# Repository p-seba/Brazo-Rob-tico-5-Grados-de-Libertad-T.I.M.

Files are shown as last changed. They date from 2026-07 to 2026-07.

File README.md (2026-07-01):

# Brazo Robótico de 5 Grados de Libertad - T.I.M.
Proyecto del Taller Inicial de Mecatrónica, Facultad de Ingeniería, UNCuyo. 

En este repositorio encontrarás todos los archivos asociados a la realización y presentación final del proyecto.    

Aplicaciones utilizadas: 
* Autodesk Fusion
* KiCad
* Visual Studio Code (PlatformIO)

En la carpeta de **Código** se encuentra una recopilación de todos los programas utilizados durante las pruebas y el código final. 

En la carpeta de **Diseño 3D** están los archivos de modelado y dos renders. Todo el diseño fue realizado por el grupo, excepto por el componente de la garra, el cual es una modificación del diseño original de **Julián Herrera**, disponible en: https://grabcad.com/library/gripper-and-servo-mg90s-1 

En la carpeta **PCB** están subidos los archivos de KiCad utilizados para diseñar las conexiones finales.  

En la carpeta **Documentación** están subidos todos los trabajos prácticos asociados a la materia y el informe final presentado en la mesa de examen. 

## Enlaces de interés 

* **Diseño en Fusion:** https://a360.co/4xZ3YgB 
* **Informe:** 

### Herramientas:
* **Autodesk Fusion:** https://www.autodesk.com/latam/products/fusion-360/overview
* **KiCad:** https://www.kicad.org/
* **Visual Studio Code:** https://code.visualstudio.com/
* **PlatformIO:** https://platformio.org/

---
Ante cualquier consulta, contactar a: joaquin.winckler@gmail.com

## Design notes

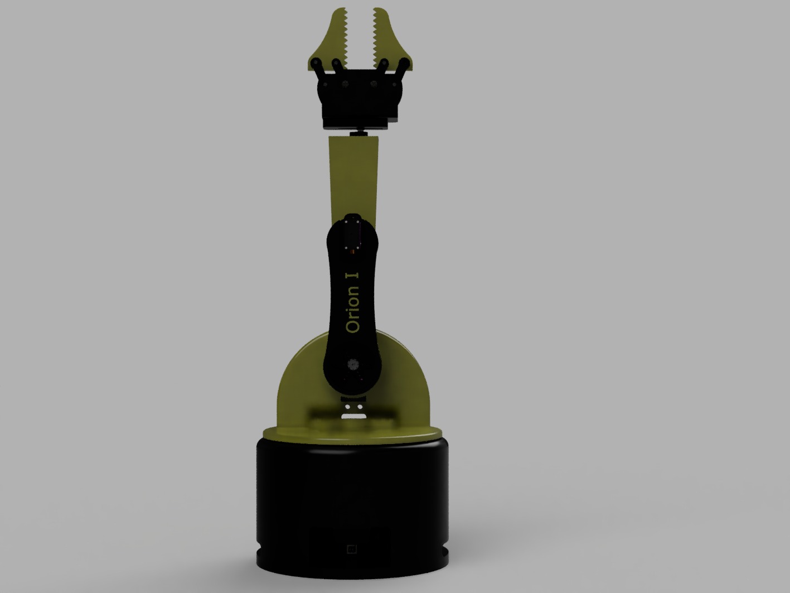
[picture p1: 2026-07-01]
Diseño 3d/Render 2.jpeg

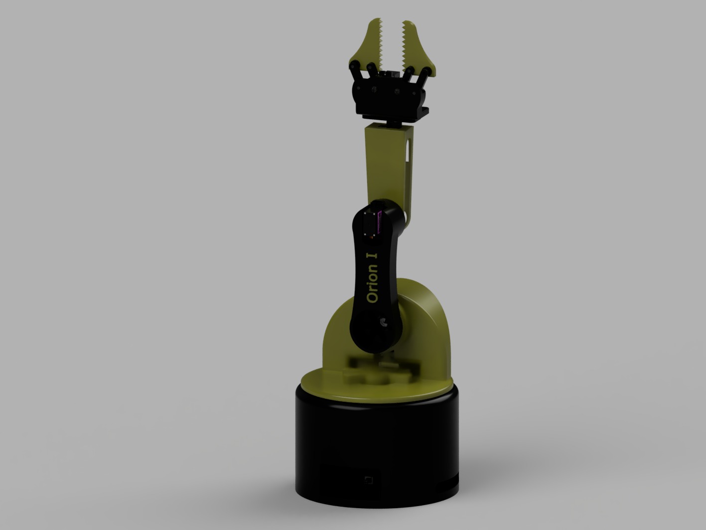
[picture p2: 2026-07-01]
Diseño 3d/Render 1.jpeg

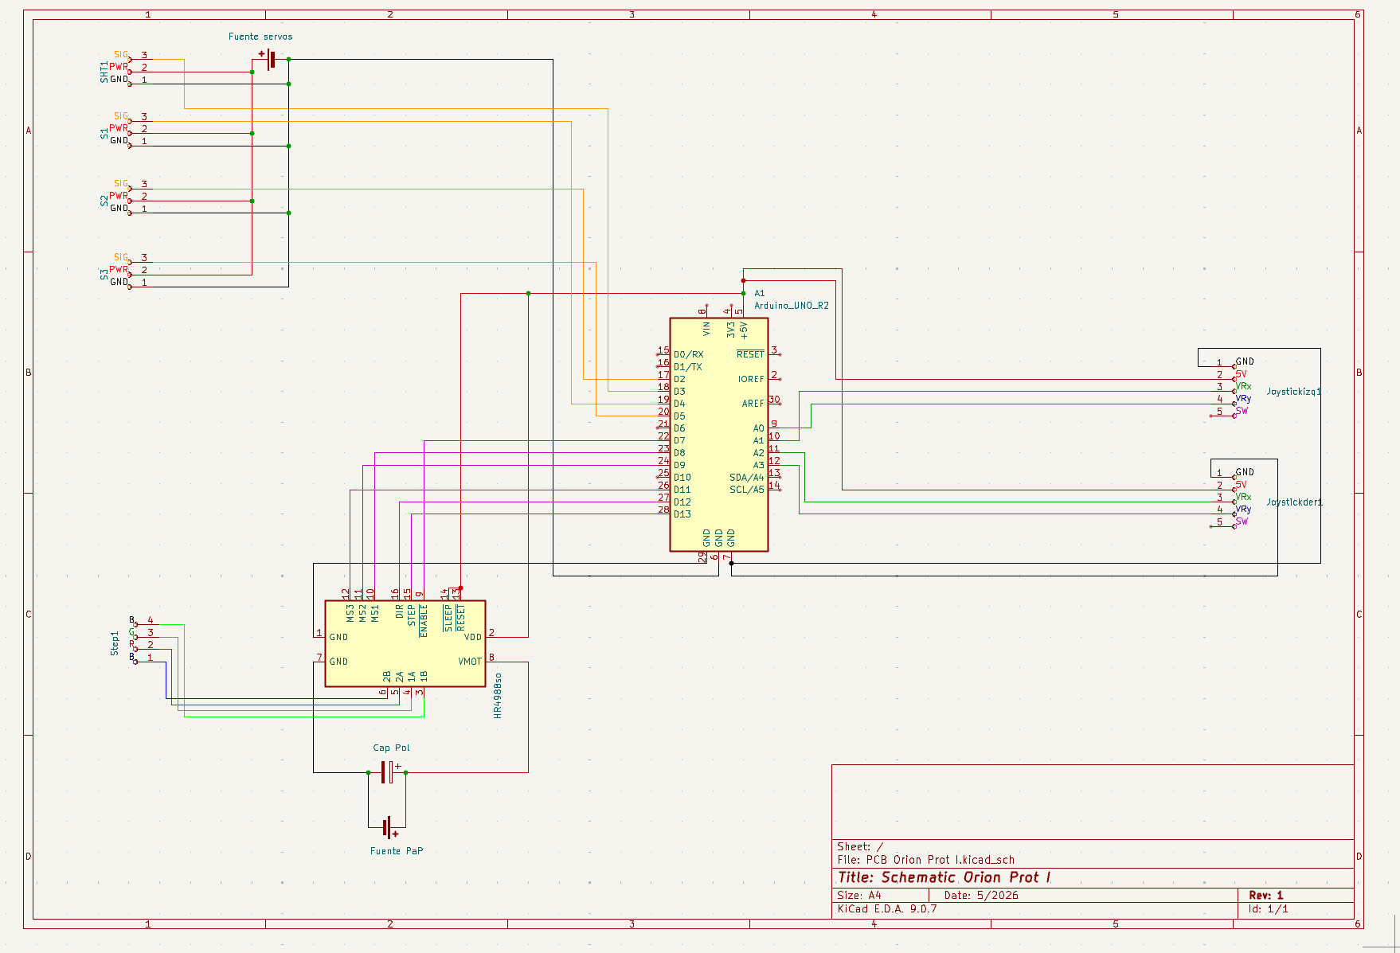
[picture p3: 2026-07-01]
PCB/Circuito.png

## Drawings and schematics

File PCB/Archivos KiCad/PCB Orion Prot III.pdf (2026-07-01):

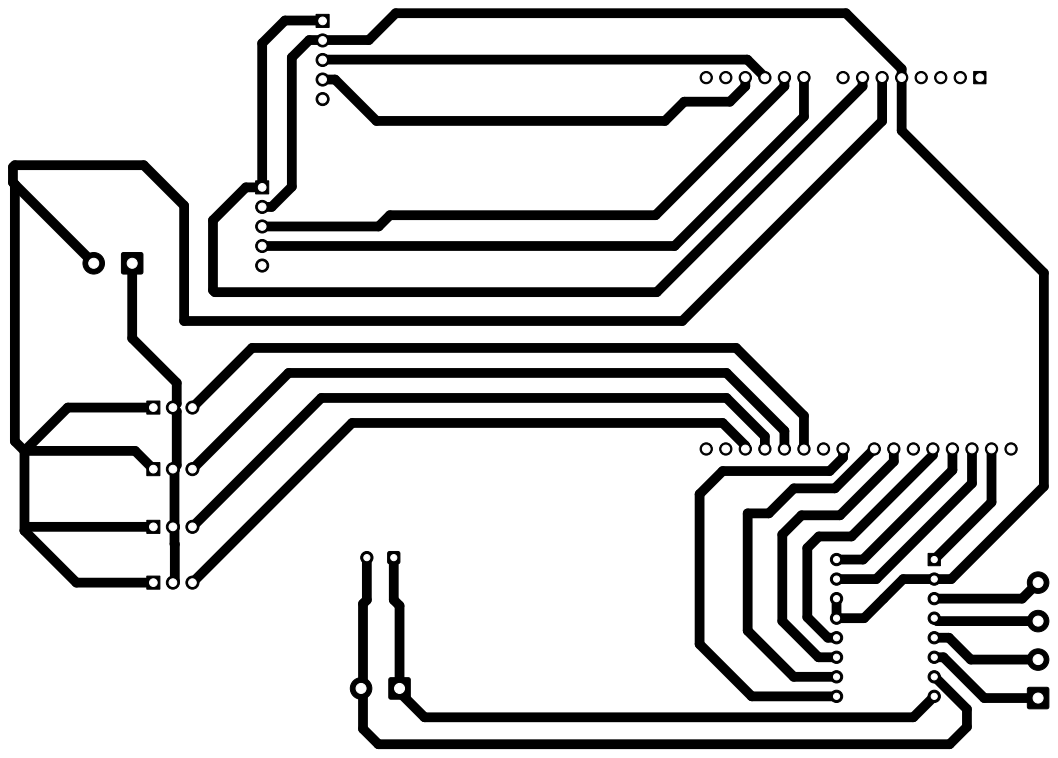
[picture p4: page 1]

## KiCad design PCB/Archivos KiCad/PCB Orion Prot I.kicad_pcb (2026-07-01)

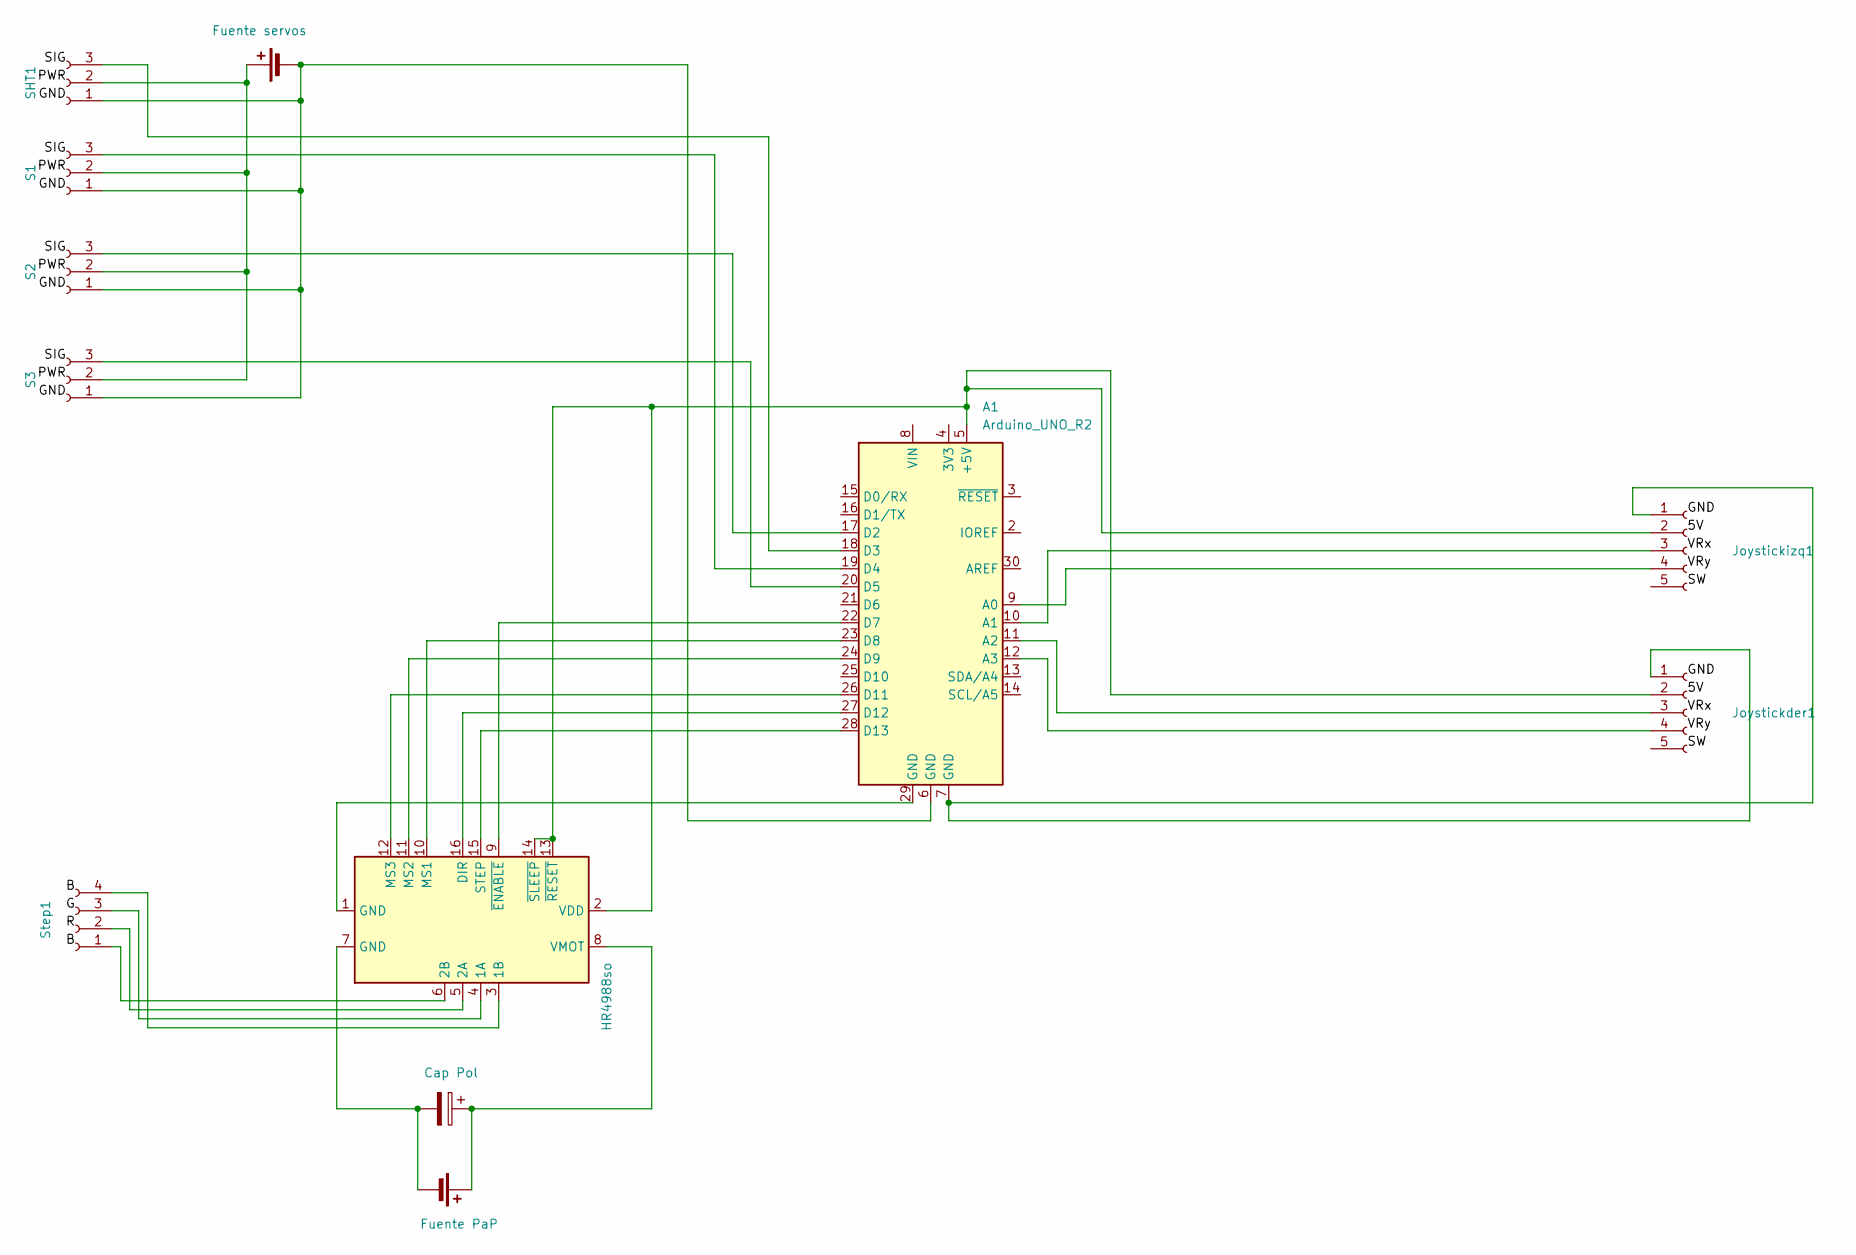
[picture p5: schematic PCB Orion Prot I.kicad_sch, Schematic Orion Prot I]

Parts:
A1: Arduino_UNO_R2
A2: HR4988so; Pololu_Breakout-16_15.2x20.3mm
BT1: Fuente servos; TerminalBlock_MaiXu_MX126-5.0-02P_1x02_P5.00mm
BT2: Fuente PaP; TerminalBlock_MaiXu_MX126-5.0-02P_1x02_P5.00mm
C2: Cap Pol; CP_Radial_D8.0mm_P3.50mm
Joystickder1: Conn_01x05_Socket; PinSocket_1x05_P2.54mm_Vertical
Joystickizq1: Conn_01x05_Socket; PinSocket_1x05_P2.54mm_Vertical
S1, S2, S3: Conn_01x03_Socket; PinHeader_1x03_P2.54mm_Vertical
SHT1: Conn_01x03_Socket; PinHeader_1x03_P2.54mm_Vertical
Step1: Conn_01x04_Socket; TerminalBlock_MaiXu_MX126-5.0-04P_1x04_P5.00mm

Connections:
unnamed: A1.5 (+5V), A2.2 (VDD), A2.13 (~RESET), A2.14 (~SLEEP), Joystickder1.2, Joystickizq1.2
unnamed: A1.9 (A0), Joystickizq1.4
unnamed: A1.10 (A1), Joystickizq1.3
unnamed: A1.11 (A2), Joystickder1.3
unnamed: A1.12 (A3), Joystickder1.4
unnamed: A1.17 (D2), S2.3
unnamed: A1.18 (D3), SHT1.3
unnamed: A1.19 (D4), S1.3
unnamed: A1.20 (D5), S3.3
unnamed: A1.22 (D7), A2.9 (~ENABLE)
unnamed: A1.23 (D8), A2.10 (MS1)
unnamed: A1.24 (D9), A2.11 (MS2)
unnamed: A1.26 (D11), A2.12 (MS3)
unnamed: A1.27 (D12), A2.16 (DIR)
unnamed: A1.28 (D13), A2.15 (STEP)
unnamed: A1.29 (GND), A2.1 (GND)
unnamed: A2.4 (1A), Step1.3
unnamed: A2.3 (1B), Step1.4
unnamed: A2.5 (2A), Step1.2
unnamed: A2.6 (2B), Step1.1
unnamed: A2.8 (VMOT), BT2.1 (+), C2.1
unnamed: BT1.1 (+), S1.2, S2.2, S3.2, SHT1.2
unnamed: A1.6 (GND), BT1.2 (-), S1.1, S2.1, S3.1, SHT1.1
unnamed: A2.7 (GND), BT2.2 (-), C2.2
unnamed: A1.7 (GND), Joystickder1.1, Joystickizq1.1

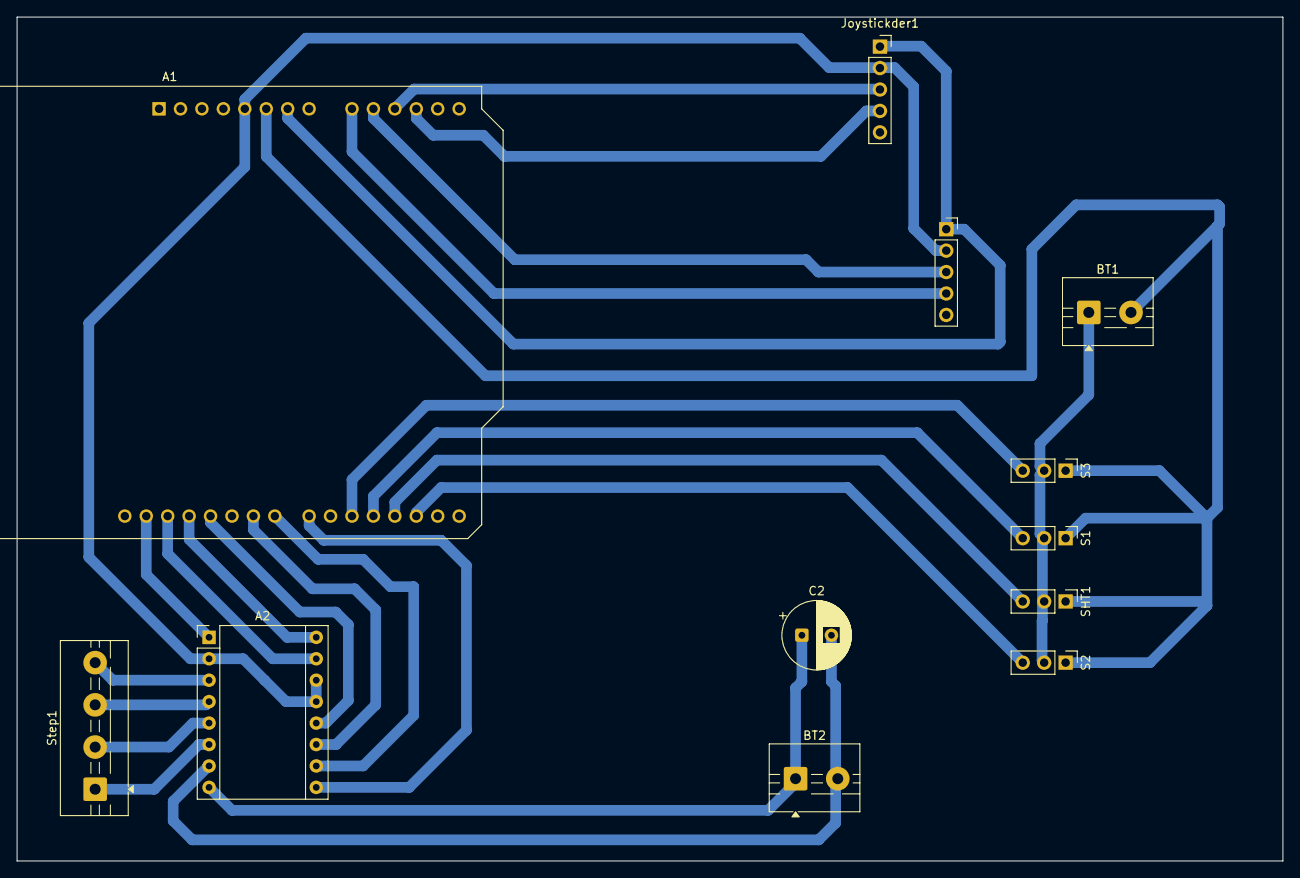
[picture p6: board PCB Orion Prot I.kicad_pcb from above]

Board: 2 copper layers, 150.0 x 100.0 mm, 12 parts (0 on the bottom side), 25 nets.

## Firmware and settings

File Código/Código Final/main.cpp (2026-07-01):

#include <Arduino.h>
#include <Servo.h>
#include <AccelStepper.h>

// SETEO JOYSTICKS

struct J{
  int j_pin; //pin al que esta conectado el joystick 
  float j_centro; // centro del joystick 
  float j_min; //valor minimo del joystick 
  float j_max; //valor maximo del joystick 
  float j_rango; //distancia del centro hasta un extremo (la menor)
  unsigned long j_lectura; //tiempo que paso desde la ultima lectura 
  const int j_tlectura; //tiempo que espera entre cada lectura
  const int j_cmedidas; //lecturas del joystick para determinar su centro 
  const int j_medidas; //cantidad de veces que se lee el joystick cada vez 
  float j_valor; //valor del joystick
  const int j_zonam; //zona muerta
  bool calibrado; //determina si se calculo el centro 
};

const int j_n = 4; //cantidad de joysticks 

J joy[j_n]{
  {A0, 512, 50, 973, 0, 0, 5, 50, 3, 0, 25, false}, //alto torque 0 
  {A1, 512, 50, 973, 0, 0, 5, 50, 3, 0, 25, false}, //1 codo sg90
  {A2, 512, 50, 973, 0, 0, 5, 50, 3, 0, 25, false}, //2 
  {A3, 512, 50, 973, 0, 0, 5, 50, 3, 0, 25, false} //3 
};

// SETEO SERVOS 

struct S{
  Servo servo; //crea el objeto Servo. 
  const int s_pin; //pin del servo 
  const int s_min; //grado minimo del servo 
  const int s_max; // grado maximo del servo 
  const int s_centro; //centro del servo 
  J* joy_ref; //puntero que almacena los datos de los joysticks 
  const int s_rango; //distancia del centro a los extremos 
  int s_posicion_a; //posicion actual del servo 
  int s_posicion_o; //posicion objetivo del servo
  const float s_vel; //cantidad de grados que se mueve por segundo
  float s_mov_grados; //movimiento en grados 
  float s_obj_grados; //movimiento objetivo en grados 
};

const int s_n = 3; //cantidad de servos asociados a movimiento 

S servos[s_n]{
  {Servo(), 8, 5, 175, 90, &joy[0], 85, 90, 90, 0.05, 0.0, 0.0}, //0
  {Servo(), 9, 5, 175, 90, &joy[1], 85, 90, 90, 0.05, 0.0, 0.0}, //1
  {Servo(), 10, 5, 175, 90, &joy[2], 85, 90, 90, 0.1, 0.0, 0.0} //2
}; 

// SETEO GARRA

struct G{
  Servo servo; //crea el objeto Servo. 
  const int g_pin; //pin del servo asociado a la garra
  const int g_min; //grado minimo de la garra
  const int g_max; //grado maximo de la garra 
  int g_posicion_a; //posicion actual del servo  
  const float g_vel; //tiempo entre cada movimiento del servo 
  const int bot_a; //pin del boton para abrir
  const int bot_c; // pin del boton para cerrar
  unsigned long t_ultimo_paso; // medicion de tiempo 
};

G garra{
  Servo(), 11, 5, 175, 90, 30, 12, 13,0
};

// SETEO MOTOR PASO A PASO
      
struct P{
  AccelStepper stepper; //crea el objeto stepper 
  const int p_enable; //prender el motor 
  const int p_dir; //determina la dirección del motor, 6
  const int p_step; //determina los pasos del motor, 5 
  const int p_ms1; //micropasos asociados al motor
  const int p_ms2; 
  const int p_ms3;
  J* joy_ref; //puntero que almacena datos de los joysticks 
  const float pv_max; //velocidad maxima 
  const float rampa; // "aceleracion"
  float v_ac; //velocidad actual 
};

P paso{
  AccelStepper(AccelStepper::DRIVER, 5 /*Step*/, 6 /*Dir*/) /*define el motor*/, 7, 6, 5, 4, 3, 2, &joy[3], 200.0, 0.08, 0.0
};

// CALIBRAR JOYSTICKS 

void calibrar(){

  //realiza el bucle, abarca los 4 joysticks 
  for ( int s = 0; s < j_n; s++){
    long sum = 0; //reinicia el valor de sum 

    for (int i = 0; i < joy[s].j_cmedidas; i++){
      sum += analogRead(joy[s].j_pin); //lee el joystick correpondiente una cierta cantidad de veces y las suma 
      delay(10); 
    }

    joy[s].j_centro = sum / joy[s].j_cmedidas; //le asigna como centro el cociente entre la suma y la cantidad de veces que se midio
    
    joy[s].j_valor = joy[s].j_centro; //inicializa el valor del joystick como su centro 

    //luego de determinar zona muerta curva 
    joy[s].j_max = 1023.0 - joy[s].j_centro - joy[s].j_zonam; //recalcula el valor maximo 
    joy[s].j_min = joy[s].j_centro - joy[s].j_zonam; //recalcula el valor minimo 

    joy[s].j_rango = min(joy[s].j_max, joy[s].j_min); //toma como que el joystick tiene el menor rango de movimiento para evitar forzar un lado
    joy[s].j_rango = joy[s].j_rango * 0.90; //utiliza solo el 90% del rango (evita que el movimiento sea mas rapido para un lado)
    joy[s].j_rango = max(joy[s].j_rango, 1.0); //evita que el rango sea 0  

  }

}

//VALOR JOYSTICKS 

float j_val (J* joy /*define la variable a partir del puntero*/) {

  //lee el joystick cada 20ms
  if (millis() /* tiempo desde que el arduino esta ejecutando codigo */ - joy->j_lectura >= joy->j_tlectura){
    joy->j_lectura = millis(); //le modifica el tiempo de la ultima lectura al joystick 
        
    long sum = 0;

    //realiza 3 lecturas del joystick 
    for (int i = 0; i < joy->j_medidas; i++){
      sum += analogRead(joy->j_pin);
    }

    joy->j_valor = sum/joy->j_medidas; //le asigna como valor final al joystick el promedio de las lecturas 
    }

  //aplica la zona muerta
  float diff = joy->j_valor - joy->j_centro; //diferencia entre el valor medido y el centro 
  float signo = (diff >= 0) ? 1.00 : -1.00; //si la diferencia es mayor que 0, le asigna 1 y si no -1 (positivo y negativo)
  float diff_a = fabs(diff) - joy->j_zonam; //cuanto "salio" el joystick de la zona muerta 

  //si el joystick se movio afuera de la zona muerta 
  if (diff_a > 0){ 
    float fraccion = diff_a / joy->j_rango; //determina el movimiento con un valor entre 0 y 1 (0 no mov, 1 se mueve todo el rango)
    fraccion = constrain(fraccion, 0.0, 1.0); //limita el valor para evitar errores 
    fraccion = pow(fraccion, 1.3); //eleva el resultado a 1.3, disminuye la sensibilidad cerca del centro 

    return (fraccion * signo); //valor final con direccion incluida. 

  }

  //si no se movio afuera de la zona muerta 
  else{ 
    return 0.0;
  }
        
}

// INICIO SERVOS 

void inicio(){

  //asigna los pines a cada uno de los motores y los mueve al centro 
  for (int i = 0; i < s_n; i++){
    servos[i].servo.attach(servos[i].s_pin); //asignacion de pines
    servos[i].s_posicion_a = servos[i].s_centro; //posicion actual = centro 
    servos[i].servo.write(90); //mueve los servos al centro 
  }

  //GARRA
  garra.servo.attach(garra.g_pin); //asigna el pine 
  garra.servo.write(garra.g_posicion_a); //mueve a la posicion inicial 
  //pines de los botones de los joysticks, resistencia interna 
  pinMode(garra.bot_a, INPUT_PULLUP); //abrir 
  pinMode(garra.bot_c, INPUT_PULLUP); //cerrar
}

// MOVIMIENTO SERVOS  

//Determina la cantidad de grados a mover, servos[h].s_posicion_o

int mover(int h, float j_valor){

  // si el joystick esta dentro de la zona muerta 
  if (fabs(j_valor) == 0.0){
    servos[h].s_posicion_o = servos[h].s_posicion_a; // posicion obj = posicion actual, no movimiento 
    servos[h].s_obj_grados = 0.0; // grados a mover = 0 
    return servos[h].s_posicion_o; // mantiene la posicion actual 
  }

  //si no esta en la zona muerta 

  servos[h].s_obj_grados += fabs(j_valor); // determina la cantidad de grados objetivos a mover, PROBAR MULTIPLICANDO POR 0.75, ETC.

  //si hay mas de un grado para mover 
  if (servos[h].s_obj_grados >= 1.0){
 
    int pasos_obj = (int)servos[h].s_obj_grados; //transforma s_obj_grados a una variable entera, solo toma la parte entera 
    servos[h].s_obj_grados -= pasos_obj;  //deja en s_obj_grados solo la parte decimal para aprovecharla en la sig iteracion 

    int nueva_pos; //define la nueva posicion del motor 

    //si se mueve para la derecha 
    if (j_valor > 0){
      nueva_pos = servos[h].s_posicion_o + pasos_obj; // Calcula la nueva posicion como la antigua posicion objetivo + la cantidad de pasos 
    } 
    //si se mueve para la izquierda 
    else {
      nueva_pos = servos[h].s_posicion_o - pasos_obj; // Calcula la nueva posicion como la antigua posicion objetivo - la cantidad de pasos 
    }

    //limita el nuevo valor de posicion a los maximos y minimos preestablecidos del servo 
    nueva_pos = constrain(nueva_pos, servos[h].s_min, servos[h].s_max);
    //limita la nueva posicion a valores cercanos a la posicion actual para evitar movimientos bruscos 
    nueva_pos = constrain(nueva_pos, servos[h].s_posicion_a - 5, servos[h].s_posicion_a + 5);

    servos[h].s_posicion_o = nueva_pos;
  }

  return servos[h].s_posicion_o; //devuelve la posicion objetivo 

}

// Realiza el movimiento, servos[i].s_posicion_a

void actualizacion(int i){

  int diff = servos[i].s_posicion_o - servos[i].s_posicion_a; //diferencia entre el obj y la actual  

  //si hay 1 grado o menos para mover 
  if (abs(diff) <= 1){
    servos[i].s_mov_grados = 0.0; //no devuelve movimiento 
    return; //pasa al siguiente motor 
  }

  //si hay movimiento, lo acumula como el ultimo movimiento + velocidad
  servos[i].s_mov_grados += servos[i].s_vel;

  // solo mueve cuando acumuló al menos 1 grado
  if (servos[i].s_mov_grados >= 1.0){

    int pasos = (int)servos[i].s_mov_grados; //guarda solo la parte entera del movimiento 
    servos[i].s_mov_grados -= pasos; // guarda la parte decimal del movimiento para futuras iteraciones 

    pasos = min(pasos, abs(diff)); //limita el paso a 5 grados 
      
    //determina para que lado se mueve y limita el movimiento 
    servos[i].s_posicion_a += (diff > 0) ? pasos : -pasos; //si la resta es positiva se mueve para la derecha, pos_ac = pos_ac + pasos, analogo izq
    servos[i].s_posicion_a = constrain(servos[i].s_posicion_a, servos[i].s_min, servos[i].s_max); //limita la nueva posicion del servo para que no salga de los limites 
    servos[i].servo.write(servos[i].s_posicion_a); //realiza el movimiento del servo 
  }
}
     
//GARRA

void agarrar(){
  
  //si pasaron 50 ms o mas entre pasos 
  if (millis() - garra.t_ultimo_paso >= garra.g_vel){

    garra.t_ultimo_paso = millis(); //actualiza el tiempo 


    if ((digitalRead(garra.bot_a) == LOW) && (digitalRead(garra.bot_c) == LOW)){
      garra.g_posicion_a = 170;  //si tocas los botones al mismo tiempo se abre la garra 
    }
    //si el boton de abrir se presiona se abre 5 grados
    else if (digitalRead(garra.bot_a) == LOW){
      garra.g_posicion_a += 5; 
    }
    //si el boton de cerrar se presiona se cierra 5 grados 
    else if (digitalRead(garra.bot_c) == LOW){
      garra.g_posicion_a -= 5;
    }

    garra.g_posicion_a = constrain(garra.g_posicion_a, garra.g_min, garra.g_max); //limita la posicion por seguridad 
    garra.servo.write(garra.g_posicion_a); //mueve la garra
  }

}

//CONFIGURACION MOTOR PASO A PASO 

void p_config(){

  //tipo de pin de los micro pasos y enable 
  pinMode(paso.p_ms1, OUTPUT); 
  pinMode(paso.p_ms2, OUTPUT);
  pinMode(paso.p_ms3, OUTPUT);
  pinMode(paso.p_enable, OUTPUT);

  //setea los micropasos a 1/4, 800 una vuelta 
  digitalWrite(paso.p_ms1, LOW);
  digitalWrite(paso.p_ms2, HIGH); 
  digitalWrite(paso.p_ms3, LOW); 

  //inicia el motor
  digitalWrite(paso.p_enable, LOW);

  //velocidades maximas y aceleración máxima 
  paso.stepper.setMaxSpeed(paso.pv_max); 

}

//MOVIMIENTO MOTOR PASO A PASO 

void p_mov(){
      
  float v = j_val(paso.joy_ref); //lee el joy asociado, val entre -1 y 1 
  float velocidad = v * paso.pv_max; //convierte el valor en una velocidad dentro del umbral
  paso.v_ac += (velocidad - paso.v_ac) * paso.rampa; //aumenta la velocidad de manera progresiva hasta llegar a la velocidad deseada 

  if (fabs(paso.v_ac) < 5.0) paso.v_ac = 0.0; //si la velocidad es muy baja lo detiene, evita movimiento por ruido

  paso.stepper.setSpeed(paso.v_ac); //le asigna la velocidad al motor 
  paso.stepper.runSpeed(); //lo mueve a esa velocidad 

}


void setup() {

  calibrar(); //calibra los centros de los joysticks 
  inicio(); //inicia los servomotores 
  p_config(); //inicia el motor 
        
}

void loop() {

  //recorre cada uno de los joysticks asociados a los servos  
  for (int i = 0; i < s_n; i++){
          
    float valor = j_val(servos[i].joy_ref); //determina el valor del joystick 

    //si el joystick se movio
    if (fabs(valor) > 0.0){
      mover(i,valor); // determina la posicion objetivo
    }

    actualizacion(i); //actualiza la posicion de los servomotores 
  
  }   
  agarrar(); //realiza el movimiento de la garra 
  p_mov(); //mueve el motor hacia alguno de los dos lados, movimiento por velocidad 
  
}
    

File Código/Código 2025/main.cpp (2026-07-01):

#include <Arduino.h>
#include <Servo.h> //librería para controlar los servos
#include <AccelStepper.h> //librería para controlar el motor paso a paso 

//define la estructura de los servos, con todas las variables de cada uno
struct S{
  Servo servo; //objeto
  int s_pin; //pin del servo
  int j_pin; //pin del joystick que lo controla
  int s_min; //angulo minimo
  int s_centro; //angulo central
  int s_max; //angulo maximo 
  float s_suav; //promedio de todas las posiciones 
  int j_centro; //val central del joystick
  unsigned long js_ultlectura; //hace cuanto fue la ultima lectura de los joy
};

const int s_n = 4; //cantidad de servomotores
const int j_medidas = 50; //cantidad de medidas para calibrar el centro 
const int  j_lecturas = 3; //lecturas del joystick 
const int j_zona = 60; //zona muerta joystick
const float suav = 0.70; //indice de suavizado, controla la "velocidad de respuesta"
bool calibrado = false; //por default sin calibrar

//crea los datos para cada servo 
S servos[s_n] ={
  {Servo(), 9, A0, 90, 90, 180, 90.0, 512, 0}, //garra del servo, pin 9, VRy pin A0 joystick 1 
  {Servo(), 10, A1, 0, 90, 180, 90.0, 512, 0}, //mano del servo, pin 10, VRx pin A1 joystick 1
  {Servo(), 11, A2, 0, 90, 180, 90.0, 512, 0}, //codo del servo, pin 11, VRy pin A2 joystick 2 
  {Servo(), 12, A2, 0, 90, 180, 90.0, 512, 0} //hombro del servo, pin 12, VRy pin A2 joystick 2 
};

//paso a paso
const int p_enable = 8; //habilitar y deshabilitar el motor 
const int p_dir = 7; //determina para que lado se mueve el motor
const int p_step = 6; //permite realizar los pasos
const int p_ms1 = 5; //determinan la cantidad de micro pasos por paso completo 
const int p_ms2 = 4; //determinan la cantidad de micro pasos por paso completo 
const int p_ms3 = 3; //determinan la cantidad de micro pasos por paso completo 

const int jp_pin = A3; //pin al que esta conectado el joystick del paso a paso
int jp_centro = 512; // determina un centro inicial para el joystick asociado al paso a paso 

const long p_vmax = 4000; //velocidad maxima
long p_pos = 0; 

AccelStepper stepper(1, p_step, p_dir); //crea el objeto paso a paso, especifica el tipo de driver (HR4988), pines a los cuales estan conectados step y dir. 
//especifica estos pines porque para controlar el paso a paso con el driver son necesarios esos pines. 

int p_jvalor = 0; //lectura del joystick para el paso a paso. 
long p_vel = 0; //velocidad incial 
unsigned long j_ultlectura = 0; //tiempo desde la ultima lectura
bool p_habilitado = true; //determina si esta prendido o no el motor 

//configuracion inicial del paso a paso. 
void p_config(){

  //Pines y funcion como salida 
  pinMode(p_ms1, OUTPUT);
  pinMode(p_ms2, OUTPUT);
  pinMode(p_ms3, OUTPUT);
  pinMode(p_enable, OUTPUT);

  //establece los micropasos como 1/4, 800 micropasos una vuelta. 
  digitalWrite(p_ms1, LOW);
  digitalWrite(p_ms2, HIGH);
  digitalWrite(p_ms3, LOW);

  digitalWrite(p_enable, LOW); //prende el motor. 
  p_habilitado = true; //avisa que esta prendido 

  stepper.setMaxSpeed(p_vmax); //establece una velocidad maxima 
  stepper.setAcceleration(2000); //establece una aceleracion maxima 

}

//funcion para calibrar el centro de los servos
void calibrar(){

  //repite el proceso para cada servo
  for (int s = 0; s < s_n; s++){
    long sum = 0; //reinicia el valor de sum

    //realiza 50 lecturas del valor del joystick cuando los servos estan quietos
    for (int i = 0; i < j_medidas; i++){
      sum += analogRead(servos[s].j_pin); //lecturas
      delay(10);
    }

    servos[s].j_centro = sum / j_medidas; //redefine el centro del joystick como el promedio

    //si un joystick esta muy desfasado le impone un centro 
    if (servos[s].j_centro < 485 || servos[s].j_centro > 539){
      servos[s].j_centro = 512; //cambiar para que el centro que le imponga sea el promedio de los otros centros
    }

  }

  long sum = 0; //reinicia el valor de sum

  //realiza las 50 lecturas del joy para el paso a paso 
  for(int a = 0; a < j_medidas; a++){

    sum += analogRead(jp_pin);
    delay(10);

  }

  jp_centro = sum / j_medidas; //calcula el centro del joy asociado al paso a paso 

  //si el centro esta muy desfasado le impone un centro
  if (jp_centro < 485 || jp_centro > 539){

    jp_centro = 512;

  } 

  calibrado = true; //avisa que esta calibrado

}

//elimina el ruido de los valores del joystick 
int j_val(int j_pin){ 

  long sum = 0; 

  //lee el joystick 3 veces
  for (int i = 0; i < j_lecturas; i++){
    sum += analogRead(j_pin);
    delay(1);
  }

  //le da al int el valor del promedio de las 3 lecturas
  return sum / j_lecturas; 
}

//elimina el ruido de los valores del joystick asociado al paso a paso. 
int jp_val(){

  long sum = 0;

  //lee el joystick 3 veces 
  for (int a = 0; a < j_lecturas; a++){
    sum += analogRead(jp_pin); 
    delay(1);
  }

  //le da el valor del promedio de las lecturas 
  return sum / j_lecturas;
}


//define la curva de movimiento del servo segun el movimiento del joystick
float curva (float input /* crea un float para reasignarlo */){
  return pow(input , 1.2); //le da al float el resultado de input elevado a 1.2 
} //baja la sensibilidad cerca del centro y la aumenta en los extremos 

float curva_p (float input /* crea un float para reasignarlo */){
  return pow(input , 1.6); //le da al float el resultado de input elevado a 1.2 
} //baja la sensibilidad cerca del centro y la aumenta en los extremos
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
